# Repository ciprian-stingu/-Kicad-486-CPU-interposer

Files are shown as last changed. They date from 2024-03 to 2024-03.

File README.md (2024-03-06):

# Kicad-486-CPU-interposer
**486 Cpu Interposer**  
This interposer can be used to troubleshoot not working motherboards which have Socket3/PGA168 sockets.  
All i486 CPU signals are accesible on board connectors. It **should** be compatible with Intel/AMD 486DX/SX/DX2/DX4.  
On DX/SX and DX2 processors, J1 should be connected to VCC but on DX4 it may not be needed.  
The interposer was tested using an Intel 486DX processor.

## Requirements
[Kicad-486-CPU-socket](https://github.com/ciprian-stingu/Kicad-486-CPU-socket)

## PCB options:
* Material : FR-4, TG130 
* Layers : 2 
* Thickness : 1.0 mm

## Construction
Use round female pin header (1x40 pins, step 2.54mm) to construct the socket, starting from inside to the outside.  
After each row from top, solder to the undeside, pins extracted from round female pin header. Because the thickness of the board is only 1 mm, you will not have any problems soldering them on underside.

## Images
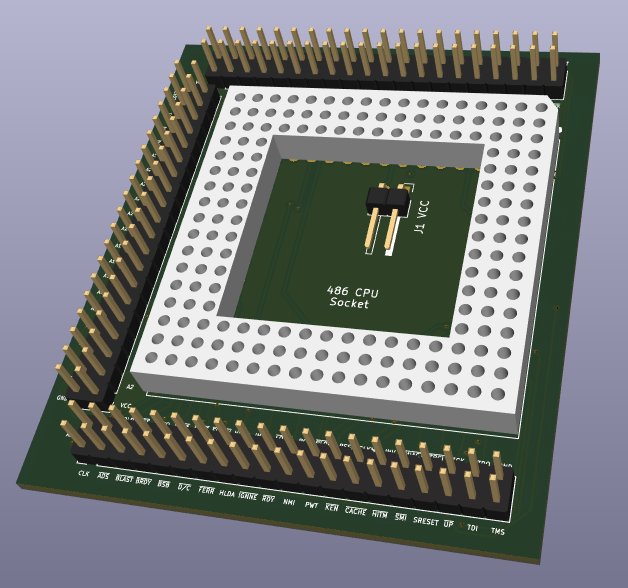
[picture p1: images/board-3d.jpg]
3D view

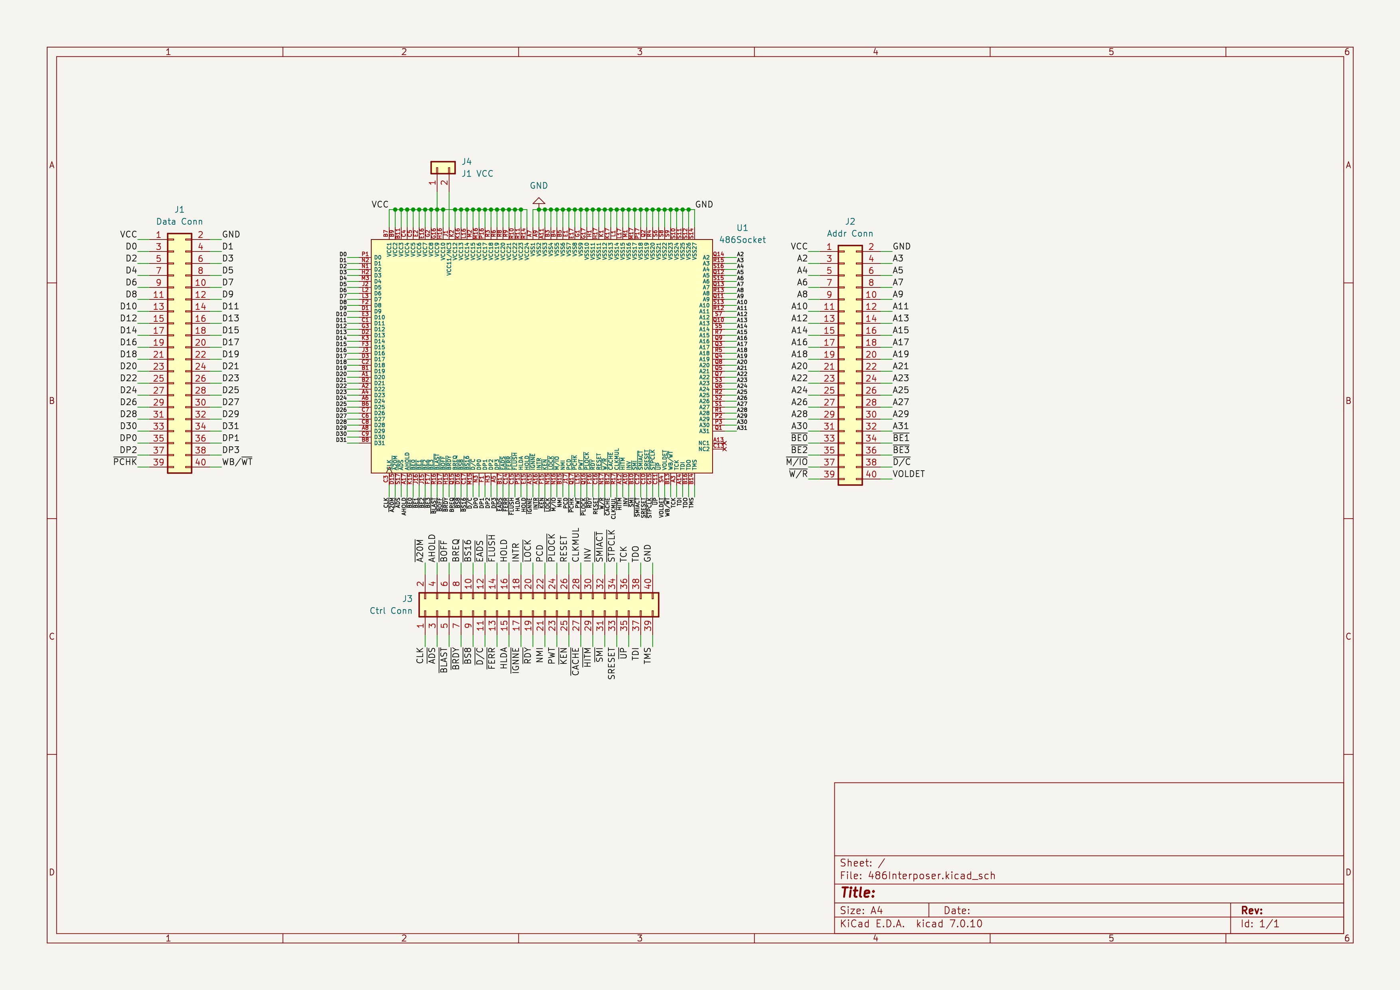
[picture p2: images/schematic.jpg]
Schematic

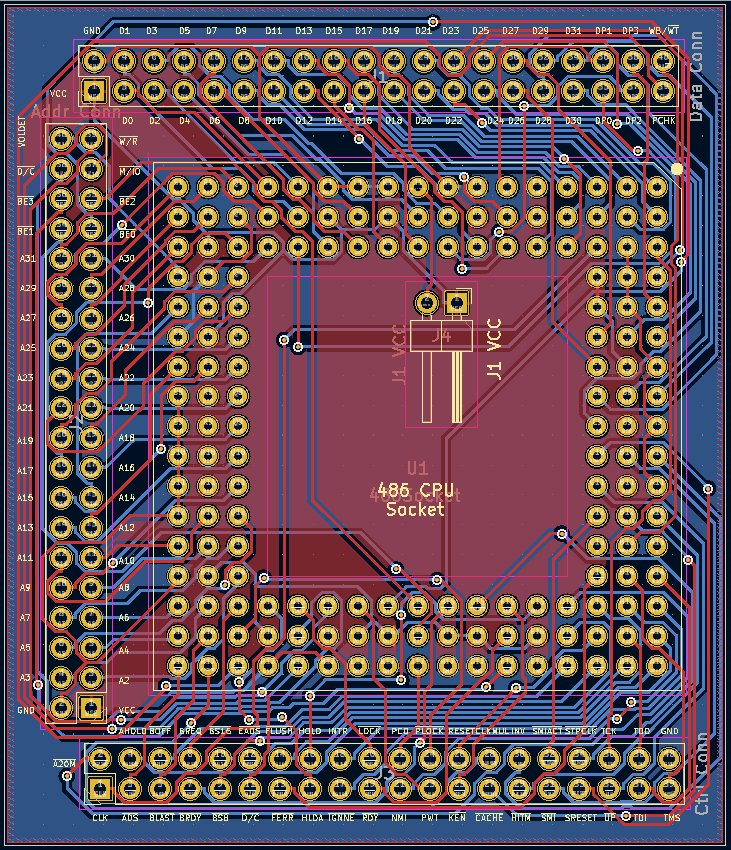
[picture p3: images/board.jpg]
PCB

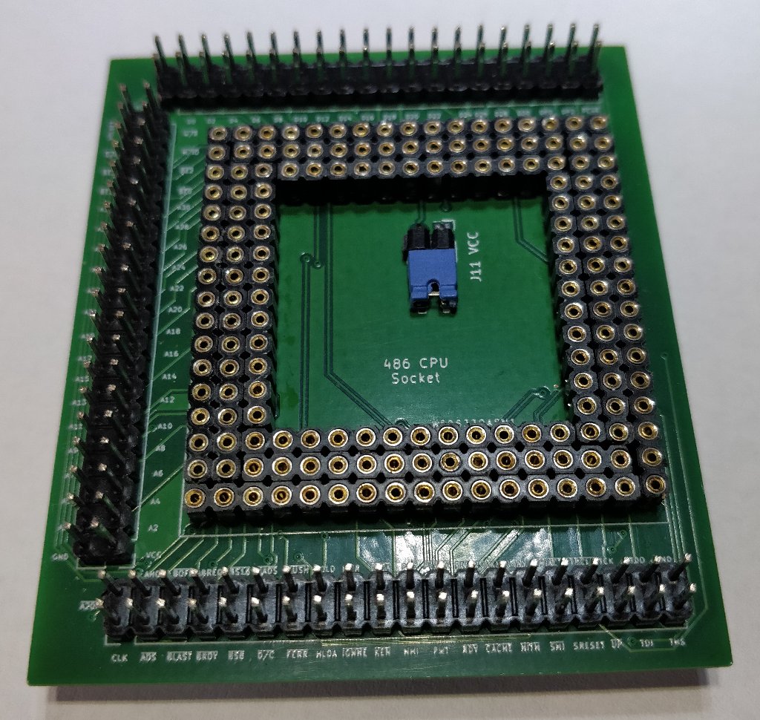
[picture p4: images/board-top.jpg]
Top

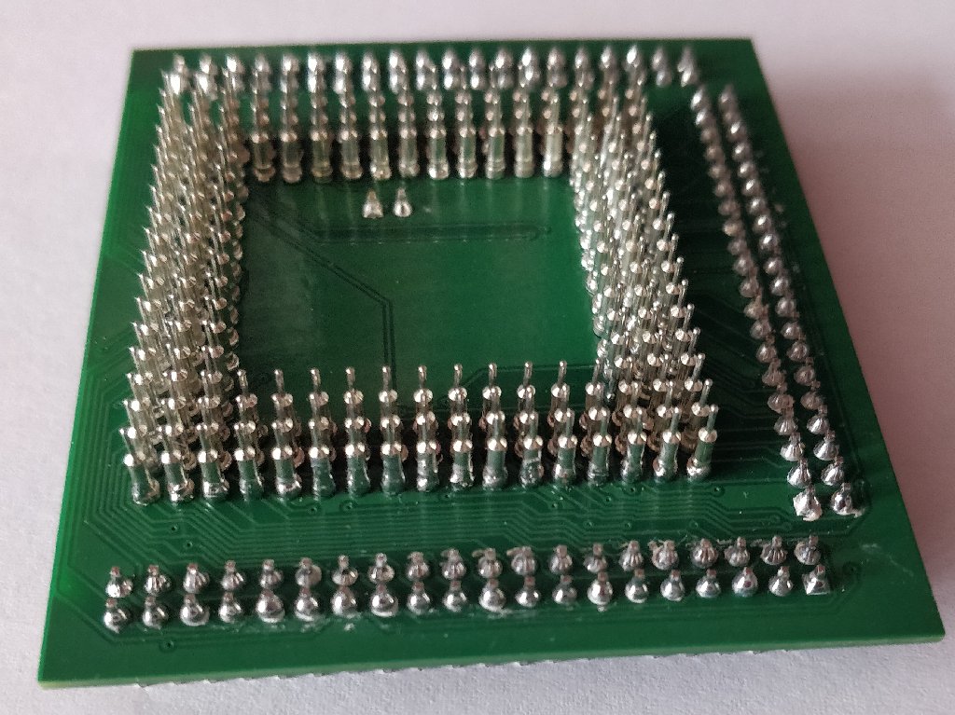
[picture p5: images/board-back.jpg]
Bottom

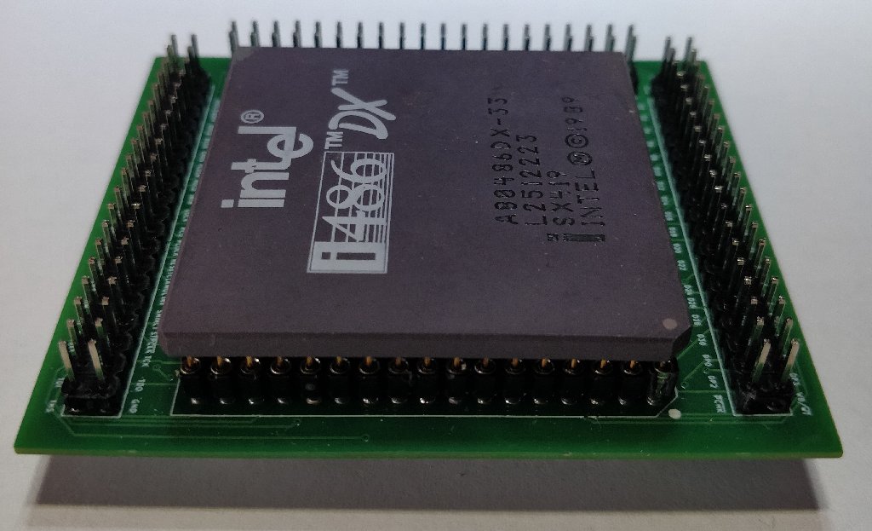
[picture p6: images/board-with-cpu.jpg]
With CPU


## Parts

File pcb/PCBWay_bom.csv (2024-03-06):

designator | quantity | value | pack | mpn | mount_type
J1 | 1 | Data Conn | PinHeader_2x20_P2.54mm_Vertical |  | tht
J2 | 1 | Addr Conn | PinHeader_2x20_P2.54mm_Vertical |  | tht
J3 | 1 | Ctrl Conn | PinHeader_2x20_P2.54mm_Vertical |  | tht
J4 | 1 | J1 VCC | PinHeader_1x02_P2.54mm_Horizontal |  | tht
U1 | 1 | 486Socket | 486Socket |  | tht

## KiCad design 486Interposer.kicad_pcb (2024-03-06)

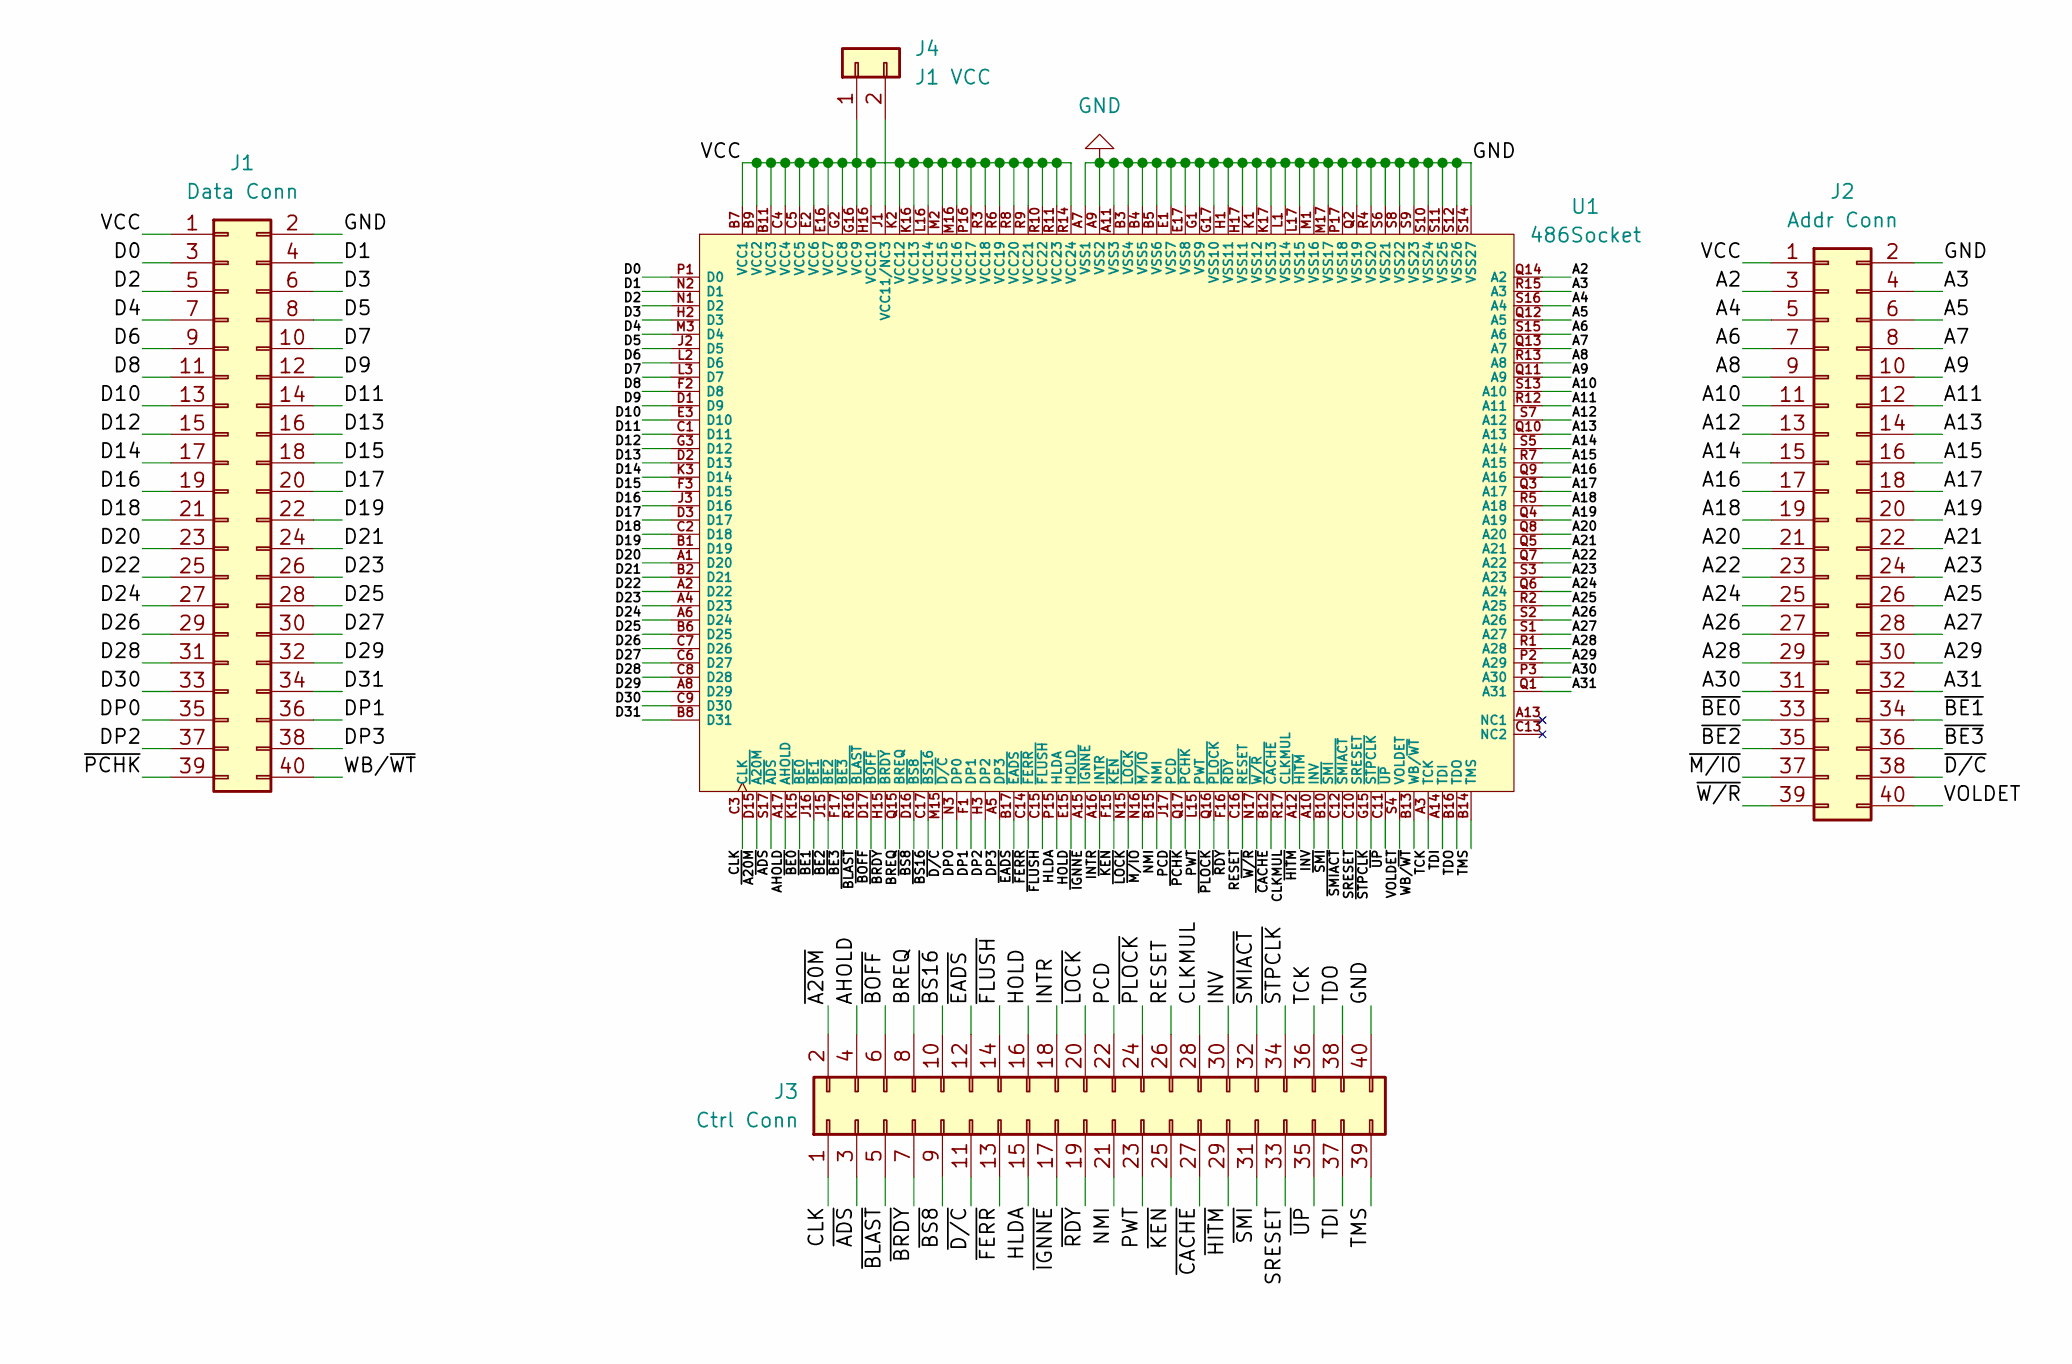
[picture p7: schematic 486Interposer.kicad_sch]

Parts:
J1: Data Conn; PinHeader_2x20_P2.54mm_Vertical
J2: Addr Conn; PinHeader_2x20_P2.54mm_Vertical
J3: Ctrl Conn; PinHeader_2x20_P2.54mm_Vertical
J4: J1 VCC; PinHeader_1x02_P2.54mm_Horizontal
U1: 486Socket

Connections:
/A2: J2.3, U1.Q14 (A2)
/A3: J2.4, U1.R15 (A3)
/A4: J2.5, U1.S16 (A4)
/A5: J2.6, U1.Q12 (A5)
/A6: J2.7, U1.S15 (A6)
/A7: J2.8, U1.Q13 (A7)
/A8: J2.9, U1.R13 (A8)
/A9: J2.10, U1.Q11 (A9)
/A10: J2.11, U1.S13 (A10)
/A11: J2.12, U1.R12 (A11)
/A12: J2.13, U1.S7 (A12)
/A13: J2.14, U1.Q10 (A13)
/A14: J2.15, U1.S5 (A14)
/A15: J2.16, U1.R7 (A15)
/A16: J2.17, U1.Q9 (A16)
/A17: J2.18, U1.Q3 (A17)
/A18: J2.19, U1.R5 (A18)
/A19: J2.20, U1.Q4 (A19)
/A20: J2.21, U1.Q8 (A20)
/A21: J2.22, U1.Q5 (A21)
/A22: J2.23, U1.Q7 (A22)
/A23: J2.24, U1.S3 (A23)
/A24: J2.25, U1.Q6 (A24)
/A25: J2.26, U1.R2 (A25)
/A26: J2.27, U1.S2 (A26)
/A27: J2.28, U1.S1 (A27)
/A28: J2.29, U1.R1 (A28)
/A29: J2.30, U1.P2 (A29)
/A30: J2.31, U1.P3 (A30)
/A31: J2.32, U1.Q1 (A31)
/AHOLD: J3.4, U1.A17 (AHOLD)
/BREQ: J3.8, U1.Q15 (BREQ)
/CLK: J3.1, U1.C3 (CLK)
/CLKMUL: J3.28, U1.R17 (CLKMUL)
/D0: J1.3, U1.P1 (D0)
/D1: J1.4, U1.N2 (D1)
/D2: J1.5, U1.N1 (D2)
/D3: J1.6, U1.H2 (D3)
/D4: J1.7, U1.M3 (D4)
/D5: J1.8, U1.J2 (D5)
/D6: J1.9, U1.L2 (D6)
/D7: J1.10, U1.L3 (D7)
/D8: J1.11, U1.F2 (D8)
/D9: J1.12, U1.D1 (D9)
/D10: J1.13, U1.E3 (D10)
/D11: J1.14, U1.C1 (D11)
/D12: J1.15, U1.G3 (D12)
/D13: J1.16, U1.D2 (D13)
/D14: J1.17, U1.K3 (D14)
/D15: J1.18, U1.F3 (D15)
/D16: J1.19, U1.J3 (D16)
/D17: J1.20, U1.D3 (D17)
/D18: J1.21, U1.C2 (D18)
/D19: J1.22, U1.B1 (D19)
/D20: J1.23, U1.A1 (D20)
/D21: J1.24, U1.B2 (D21)
/D22: J1.25, U1.A2 (D22)
/D23: J1.26, U1.A4 (D23)
/D24: J1.27, U1.A6 (D24)
/D25: J1.28, U1.B6 (D25)
/D26: J1.29, U1.C7 (D26)
/D27: J1.30, U1.C6 (D27)
/D28: J1.31, U1.C8 (D28)
/D29: J1.32, U1.A8 (D29)
/D30: J1.33, U1.C9 (D30)
/D31: J1.34, U1.B8 (D31)
/DP0: J1.35, U1.N3 (DP0)
/DP1: J1.36, U1.F1 (DP1)
/DP2: J1.37, U1.H3 (DP2)
/DP3: J1.38, U1.A5 (DP3)
/HLDA: J3.15, U1.P15 (HLDA)
/HOLD: J3.16, U1.E15 (HOLD)
/INTR: J3.18, U1.A16 (INTR)
/INV: J3.30, U1.A10 (INV)
/NMI: J3.21, U1.B15 (NMI)
/PCD: J3.22, U1.J17 (PCD)
/PWT: J3.23, U1.L15 (PWT)
/RESET: J3.26, U1.C16 (RESET)
/SRESET: J3.33, U1.C10 (SRESET)
/TCK: J3.36, U1.A3 (TCK)
/TDI: J3.37, U1.A14 (TDI)
/TDO: J3.38, U1.B16 (TDO)
/TMS: J3.39, U1.B14 (TMS)
/VCC: J1.1, J2.1, J4.1, U1.B7 (VCC1), U1.B9 (VCC2), U1.B11 (VCC3), U1.C4 (VCC4), U1.C5 (VCC5), U1.E2 (VCC6), U1.E16 (VCC7), U1.G2 (VCC8), U1.G16 (VCC9), U1.H16 (VCC10), U1.K2 (VCC12), U1.K16 (VCC13), U1.L16 (VCC14), U1.M2 (VCC15), U1.M16 (VCC16), U1.P16 (VCC17), U1.R3 (VCC18), U1.R6 (VCC19), U1.R8 (VCC20), U1.R9 (VCC21), U1.R10 (VCC22), U1.R11 (VCC23), U1.R14 (VCC24)
/VOLDET: J2.40, U1.S4 (VOLDET)
/WB/~WT: J1.40, U1.B13 (WB/~WT)
/~A20M: J3.2, U1.D15 (~A20M)
/~ADS: J3.3, U1.S17 (~ADS)
/~BE0: J2.33, U1.K15 (~BE0)
/~BE1: J2.34, U1.J16 (~BE1)
/~BE2: J2.35, U1.J15 (~BE2)
/~BE3: J2.36, U1.F17 (~BE3)
/~BLAST: J3.5, U1.R16 (~BLAST)
/~BOFF: J3.6, U1.D17 (~BOFF)
/~BRDY: J3.7, U1.H15 (~BRDY)
/~BS8: J3.9, U1.D16 (~BS8)
/~BS16: J3.10, U1.C17 (~BS16)
/~CACHE: J3.27, U1.B12 (~CACHE)
/~D/C: J2.38, J3.11, U1.M15 (~D/C)
/~EADS: J3.12, U1.B17 (~EADS)
/~FERR: J3.13, U1.C14 (~FERR)
/~FLUSH: J3.14, U1.C15 (~FLUSH)
/~HITM: J3.29, U1.A12 (~HITM)
/~IGNNE: J3.17, U1.A15 (~IGNNE)
/~KEN: J3.25, U1.F15 (~KEN)
/~LOCK: J3.20, U1.N15 (~LOCK)
/~M/IO: J2.37, U1.N16 (~M/IO)
/~PCHK: J1.39, U1.Q17 (~PCHK)
/~PLOCK: J3.24, U1.Q16 (~PLOCK)
/~RDY: J3.19, U1.F16 (~RDY)
/~SMIACT: J3.32, U1.C12 (~SMIACT)
/~SMI: J3.31, U1.B10 (~SMI)
/~STPCLK: J3.34, U1.G15 (~STPCLK)
/~UP: J3.35, U1.C11 (~UP)
/~W/R: J2.39, U1.N17 (~W/R)
GND: J1.2, J2.2, J3.40, U1.A7 (VSS1), U1.A9 (VSS2), U1.A11 (VSS3), U1.B3 (VSS4), U1.B4 (VSS5), U1.B5 (VSS6), U1.E1 (VSS7), U1.E17 (VSS8), U1.G1 (VSS9), U1.G17 (VSS10), U1.H1 (VSS11), U1.H17 (VSS11), U1.K1 (VSS12), U1.K17 (VSS13), U1.L1 (VSS14), U1.L17 (VSS15), U1.M1 (VSS16), U1.M17 (VSS17), U1.P17 (VSS18), U1.Q2 (VSS19), U1.R4 (VSS20), U1.S6 (VSS21), U1.S8 (VSS22), U1.S9 (VSS23), U1.S10 (VSS24), U1.S11 (VSS25), U1.S12 (VSS26), U1.S14 (VSS27)
unnamed: J4.2, U1.J1 (VCC11/NC3)

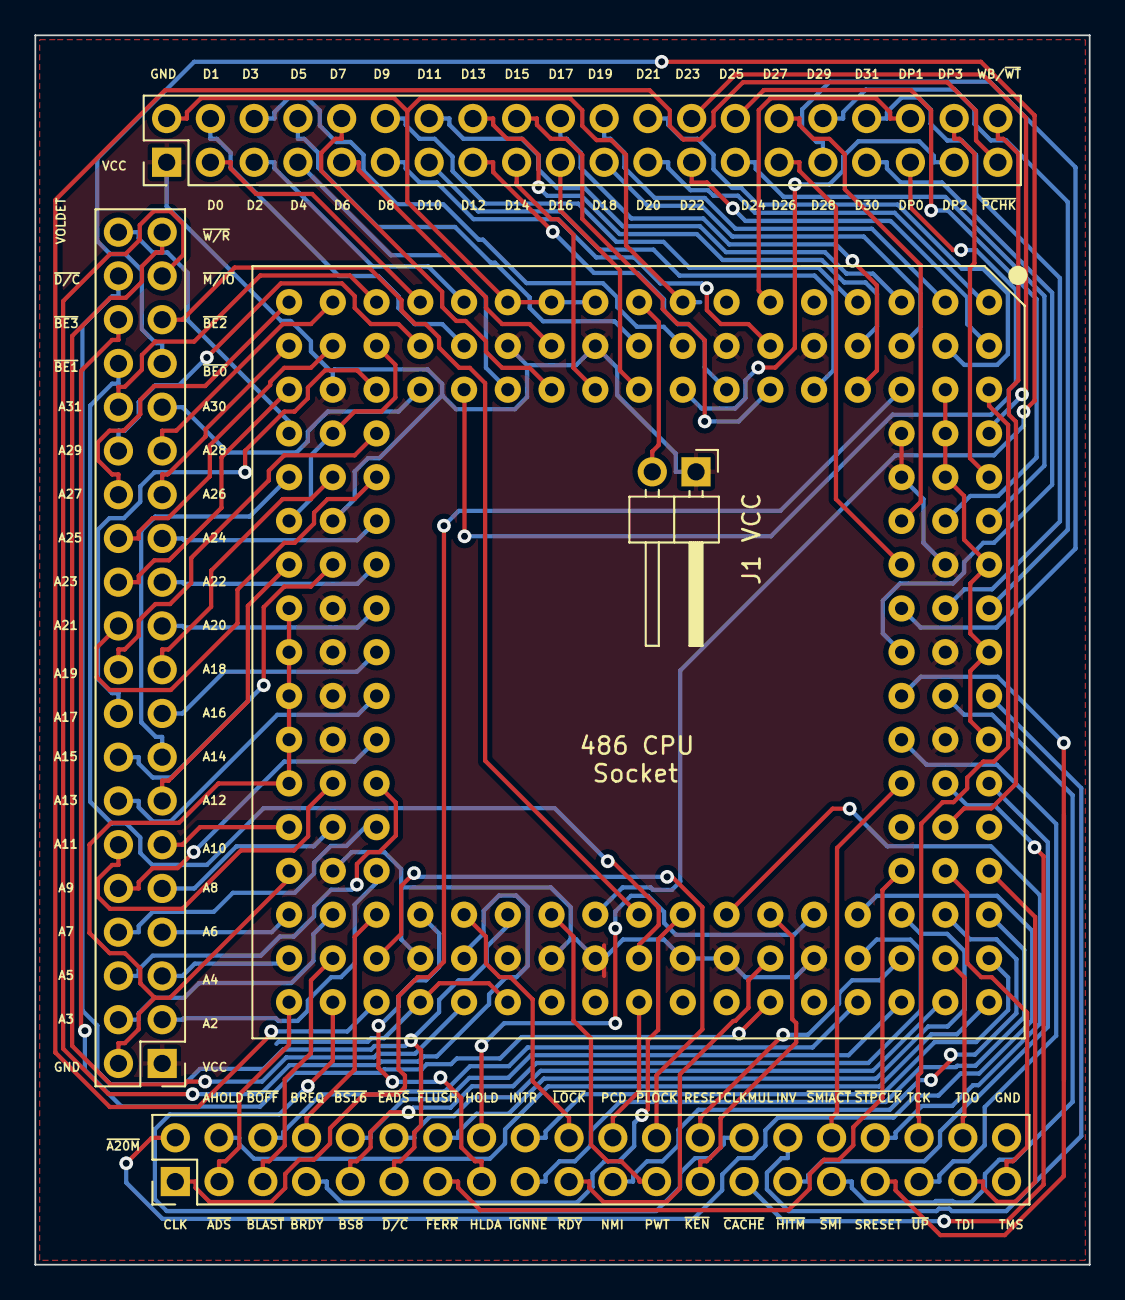
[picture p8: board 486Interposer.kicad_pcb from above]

Board: 2 copper layers, 61.2 x 71.4 mm, 5 parts (0 on the bottom side), 117 nets.
